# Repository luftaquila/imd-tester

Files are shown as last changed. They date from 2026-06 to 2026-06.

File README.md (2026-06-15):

# IMD Tester

Insulation-fault simulator for verifying Insulation Monitoring Devices (IMD): switches a known resistance between an HV rail and chassis to confirm the IMD trips at its rated threshold. Uses a FNIRSI LCR-ST1 as the ohmmeter.

## Threshold

```
R_th = 250 Ω/V × U_max
```

## Bill of materials

| # | Item | Spec | Qty |
| - | ---- | ---- | --- |
| 1 | LA42DWQ-22 pot | 200 kΩ, 22 mm panel | 1 |
| 2 | Banana jack, 4 mm | red + black, Ø8 mm hole | 2 |
| 3 | Banana cable | red/black pair, clip leads | 1 |
| 4 | MTS-203 toggle | DPDT, ON-OFF-ON, 6 mm bushing | 1 |
| 5 | FNIRSI LCR-ST1 | tweezer LCR meter | 1 |
| 6 | 3D-printed housing | shell + baseplate + button (`housing.scad`) | 1 set |
| 7 | M2 self-tapping screw | ~6 mm, pan/cap head | 4 |

## Circuit

- Pot as rheostat (W + CCW; CW tied to W).
- DPDT toggle routes both pot terminals to one destination:
  - **MEASURE** — LCR-ST1 terminals (set R, HV-isolated)
  - **OFF** (centre) — all open
  - **TEST** — banana jacks (to system)

| Toggle | Net |
| --- | --- |
| COM A / COM B | pot W / pot CCW |
| MEASURE | LCR pad 1 / pad 2 |
| TEST | banana RED / BLACK |

Verify lever→lug mapping and that centre is fully open with a multimeter.

## Procedure

1. **OFF**, cable disconnected.
2. **MEASURE** — set knob to R_th, read on LCR-ST1.
3. **OFF**.
4. Connect RED → HV, BLACK → chassis/GLV.
5. **TEST** briefly; observe IMD response.
6. **OFF**, then disconnect.

## Safety

- Set the resistance in MEASURE (HV-isolated); only TEST connects to the system.
- TEST applies the resistance across live HV — follow HV work procedures.

## Housing (`housing.scad`)

Parametric, 3 printed parts. The LCR-ST1 docks face-up (screen through the top window), inserted from the open bottom; the baseplate closes it with 4 corner M2 self-tapping screws.

- **shell** — top panel + walls; holes for pot (Ø22.5 + anti-rotation notch), toggle (Ø6.2), 2 banana jacks (Ø8, 30 mm pitch), USB-C, display window (bezel + lip); captive-button pocket; 2 banana-plug parking sockets embedded in the front (−Y) face, bottom-right (grip the Ø9×12 plug body + Ø4 pin).
- **baseplate** — fits inside the walls; central LCR support post; 4 recessed M2 clearance holes (Ø1.75 pilot in the shell bosses).
- **button** — captive plunger pressing the LCR power button.

```bash
openscad -D 'part="shell"'     -o shell.stl     housing.scad
openscad -D 'part="baseplate"' -o baseplate.stl housing.scad
openscad -D 'part="button"'    -o button.stl    housing.scad
```

Other `part` values: `preview`, `assembly`, `interference`. Edit the parameter block to match measured parts before printing.

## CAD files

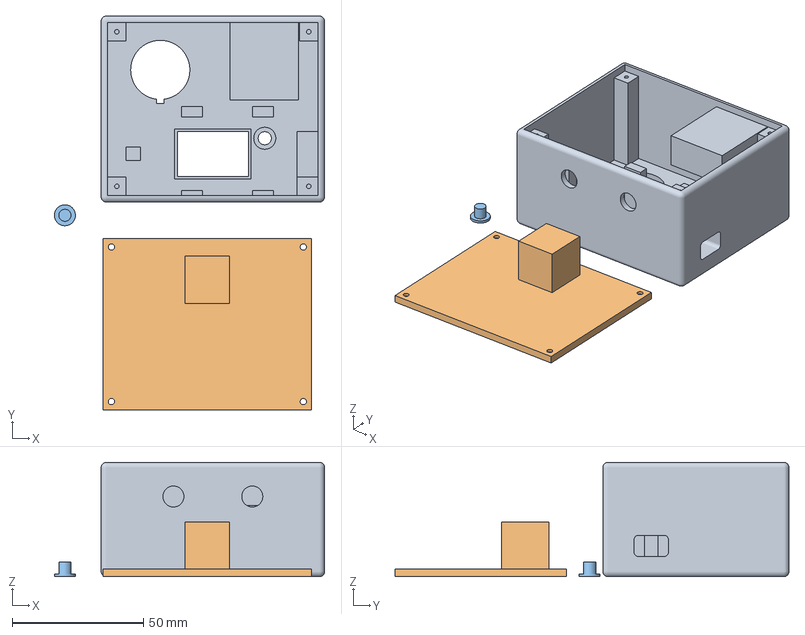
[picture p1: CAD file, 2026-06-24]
housing.3mf
102.8 x 149.9 x 43.5 mm
housing.stl_1
housing.stl_2
housing.stl_3

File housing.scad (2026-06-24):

// ============================================================
//  IMD Tester — integrated enclosure (flat top, no step)
//
//  3 printed parts:
//    shell     : top + walls, OPEN bottom (뚜껑 + 옆면)
//    baseplate : closes the bottom, fits inside the walls (바닥판)
//                4 corner M2 self-tap bolts (heads recessed) + 1 central LCR-support post
//    button    : captive LCR power-button plunger
//
//  Layout: LCR-ST1 in the +Y (back) half, screen up through the top window.
//  Pot + toggle on the top, -Y (front) strip, straddling the X-centre. Banana
//  jacks on the +Y (back) wall; a 2-socket banana-plug parking holder is
//  embedded in the -Y (front) face (bottom-right). Flat top (the pot's ~36 mm
//  body is swallowed by the box height — no step / tower).
//
//  Tweezer ARMS removed by the user, so the box length = LCR body + a small -X
//  wiring lead (measurement wires exit the LCR's -X end). The LCR is raised on
//  a baseplate post so its face seats on the bezel fence, 1.0 mm below the top
//  window; the captive power button is captured in a local panel counterbore.
//
//  Device frame: X = LCR length (+X = USB-C end), Y = width, Z = up.
//  VERIFY all dimensions against the real parts.
// ============================================================

/* [Part selection] */
part = "assembly"; // [shell, baseplate, button, assembly, preview, interference]

/* [LCR-ST1 body] */
lcr_len  = 60;
lcr_wid  = 27.8;
lcr_hi   = 19.2;
lcr_lead = 12;  // -X wiring lead room — trimmed so the screen centres in X

/* [Shell] */
wall      = 2.5;
top_th    = 2.5;
plate_th  = 3.0;
plate_fit = 0.3;

/* [Pot — LA42DWQ-22, top-mounted in the -Y strip] */
pot_depth   = 36;   // body behind the panel
pot_body_d  = 29;   // body diameter inside the box (안쪽, measured)
pot_knob_d  = 31;   // knob outer diameter above the panel (바깥, measured)
pot_clear   = 2;    // gap below the pot body
pot_hole_d  = 22.5; // panel bushing cutout
pot_notch_w = 3;    // anti-rotation notch
pot_notch_d = 1.5;
pot_pos     = [8, -18];  // [x, y] knob centre (balanced about X-centre 28, ±20)

/* [Toggle — MTS-203, top, -Y strip] */
tog_hole_d = 6.2;
tog_pos    = [48, -18]; // balanced about X-centre 28 (same 20 mm as the pot)

/* [Banana jacks — +Y (back) wall, below the LCR] */
jack_d     = 8;    // 7 mm passes, 10 mm flange stops (7 < Ø8 < 10)
jack_body_d = 11;  // jack body Ø inside the box (assumed) — drives support clearance
jack_pitch = 30;   // centre-to-centre
jack_depth = 20;   // jack housing depth inside the box (measured)
jack_xc    = 28;   // pair centre = housing X-centre (jacks symmetric L/R)
jack_z     = 10;   // below the LCR back (Z 18.4); jack body tucks under the LCR

/* [Banana-plug parking sockets — 2x, EMBEDDED in the -Y (front) face, bottom-right; insert +Y; grips the Ø9x12 rubber body] */
park_pin_d    = 4.0;    // contact-pin bore Ø
park_pin_len  = 18;     // contact-pin bore depth (metal pin = 18 mm)
park_grip_d   = 9.0;    // rubber-body bore Ø (per spec)
park_grip_len = 12;     // rubber-body grip length (per spec)
park_wall     = 2;      // material around the bores
park_xs       = [41, 54];// two socket X positions (side by side / horizontal), toward the right
park_z        = 7;       // socket height (low / bottom)

/* [LCR power button + captive plunger] */
pb_w_x = 4.5; pb_w_y = 6;
pb_cx  = lcr_len - 10 - pb_w_x / 2; // 47.75
pb_cy  = 5 + pb_w_y / 2;            // 8.0
pb_protrude = 0.5;
cb_flange_d = 8.0; cb_flange_h = 1.0;  // big flange (full length): bottom on the LCR button, top floats 0.5 mm below the deepened counterbore shoulder
cb_stem_d   = 4.6; cb_hole_d   = 5.0;
cb_cbore_d  = 8.4; cb_stem_out = 2.5;  // counterbore (1.0 deep = flange 0.5 + cb_play 0.5) captures the flange; stem protrudes 2.5 mm above the top

/* [LCR support post (single, centred, on the baseplate)] */
post_jack_clear = 1;  // clearance from each Ø11 jack body
// widest block that clears the two jack bodies: gap between bodies minus clearance
lcr_post_x = jack_pitch - jack_body_d - 2 * post_jack_clear;  // 17 (x 19.5..36.5)
lcr_post_y = 18;                                              // Y length of the support post

/* [Corner bolts — M2, square corner pillars] */
boss_r       = 3.5;  // pilot offset from the inner walls (= bolt hole position)
boss_sq      = 7;    // how far the square pillar reaches into the cavity
boss_pilot_d = 1.75; // M2 self-tap pilot
boss_pilot_h = 9;
m2_clear_d   = 2.4;
m2_head_d    = 4.0;
m2_head_h    = 2.0;

/* [LCR grips] */
grip_xR  = lcr_len - 13; // 47 (Y-grip stations on the long sides)
grip_xL  = 20;
grip_w   = 8;            // Y-grip width along X
grip_th  = 4;            // -Y grip rib thickness (Y) — strengthened from 2 mm (pot-limited)
xgrip_w  = 5;            // X-stop width (Y)
xstop_th = 5;            // X-stop thickness (X, butting the LCR end face)
xstop_squeeze = 0.4;     // -X stop bites this far past the LCR -X face (0.8→0.4, moved back 0.4 mm for clearance)

/* [Screen window] (display 15..41 x 5.5..22.3); bezel shrinks the cutout 1.5 mm/side */
scr_x0 = 14.5; scr_x1 = 41.5;
scr_y0 = 5.5;  scr_y1 = 22.5;

/* [Display bezel fence] thin lip on the panel underside; the LCR face seats on it,
   levelling the meter against its proud (0.5 mm) power button */
fence_h = 1.0;  // protrusion below the panel underside (LCR sits 1.0 mm below the panel)
fence_w = 1.0;  // fence wall width around the window

/* [USB-C cutout, right wall] */
usb_w = 13; usb_h = 8; usb_r = 1.5; // rounded corners (W,H +1 each, centre kept)
usb_frame_w = 2.0;                  // +X stop border around the USB (wraps the port on all sides)

/* [Edge rounding] */
edge_r  = 2;   // fillet on all outer edges (top, vertical, and bottom -Z)

/* [Engraving — recessed (음각) labels on the top] */
engrave_depth = 0.5;
txt_formula   = "250 Ω / V";
txt_sw_a      = "SET";      // +Y toggle position
txt_sw_off    = "OFF";
txt_sw_b      = "TEST";     // -Y toggle position
txt_pwr       = "PWR";
formula_pos   = [8, -34];   // below the pot

/* [Rendering] */
$fn     = 64;
explode = 45;
eps     = 0.1;

// ---------- derived heights ----------
roof_z0 = pot_depth + pot_clear;   // 38   top-panel underside
roof_z1 = roof_z0 + top_th;        // 40.5 top
face_z  = roof_z0 - fence_h;       // LCR face seats on the bezel fence, 1.0 mm below the panel
post_h  = face_z - lcr_hi;         // 18.4 LCR rests on the baseplate post at this Z

cb_flange_z0 = face_z + pb_protrude;          // flange bottom = LCR-button contact level (full-length plunger restored)
cb_flange_z1 = cb_flange_z0 + cb_flange_h;    // flange top (38.5)
cb_play      = 0.5;                            // counterbore deepened past the flange top → plunger floats 0.5 mm, no button preload
cb_cbore_z1  = cb_flange_z1 + cb_play;         // counterbore shoulder (39.0; cbore now 1.0 deep, +0.5)
cb_stem_z1   = roof_z1 + cb_stem_out;

usb_cy = lcr_wid / 2;       // width-centred
usb_z  = post_h + 11;       // 11 mm above the device back

// ---------- interior / outer ----------
cav_x0 = -lcr_lead;         // -12 (no tweezers; just wiring lead room)
cav_x1 = lcr_len + 8;       // 68 (USB-C wall pad)
cav_y0 = -36;               // front strip (pot/toggle); fits the Ø29 pot body
cav_y1 = lcr_wid + 2;       // 29.8 back

out_x0 = cav_x0 - wall; out_x1 = cav_x1 + wall;
out_y0 = cav_y0 - wall; out_y1 = cav_y1 + wall;
out_z0 = -plate_th;

// corner bolts (box corners, clear of the LCR)
boss = [
    [cav_x0 + boss_r, cav_y0 + boss_r],
    [cav_x1 - boss_r, cav_y0 + boss_r],
    [cav_x0 + boss_r, cav_y1 - boss_r],
    [cav_x1 - boss_r, cav_y1 - boss_r],
];

// ---------- shell ----------

module rounded_outer() { // box with ALL edges rounded (top, vertical, and bottom -Z)
    r = edge_r;
    hull() for (x = [out_x0 + r, out_x1 - r], y = [out_y0 + r, out_y1 - r]) {
        translate([x, y, roof_z1 - r]) sphere(r = r);  // top corners
        translate([x, y, out_z0 + r]) sphere(r = r);   // bottom corners (rounded -Z)
    }
}

module engrave(str, pos, sz) { // recessed text on the top surface
    translate([pos[0], pos[1], roof_z1 - engrave_depth])
        linear_extrude(engrave_depth + 1)
            text(str, size = sz, halign = "center", valign = "center",
                 font = "Liberation Sans:style=Bold");
}

module grip(xc, side) { // Y-grip: rib hugging a LONG side of the LCR
    th    = (side < 0) ? grip_th : cav_y1 - lcr_wid; // -Y: thick rib; +Y: fills LCR↔wall gap (wall-backed)
    yEdge = (side < 0) ? 0 : lcr_wid;
    ribY  = (side < 0) ? yEdge - th : yEdge;
    translate([xc - grip_w / 2, ribY, post_h])
        cube([grip_w, th, roof_z0 - post_h]);
}
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

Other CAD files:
housing.stl

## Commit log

2026-06-13 add: IMD tester housing (OpenSCAD) and README
    Parametric 3-part enclosure (shell, baseplate, captive button) for a
    FNIRSI LCR-ST1 based insulation-fault simulator: LA42DWQ-22 pot, MTS-203
    DPDT toggle (MEASURE/OFF/TEST), 2 banana jacks. 250 Ω/V threshold.
    [housing.scad]
2026-06-15 add: banana-plug parking holder; fix stale comments/README
    - 2-socket parking holder on the +X wall (grips the Ø9x12 plug body + Ø4x18
    pin), merged with the body into one seamless rounded shell (bottom -Z
    rounded too, no crease at the junction)
    - correct stale header/inline comments and README to match the design;
    remove the unused lcr_fit parameter
    [housing.scad]
2026-06-15 change: embed the parking holder in the front (-Y) face
    - move the 2 banana-plug parking sockets from an external +X-wall block into
    the body: now an internal block in the front strip, bottom-right (only two
    holes show on the -Y face, no protrusion)
    - arrange the two sockets side by side (horizontal) at the same height
    - update header comment and README to match
    - gitignore .DS_Store
    [housing.scad]
2026-06-23 change: raise display bezel fence protrusion 0.4 -> 1.0 mm
    LCR face now seats 1.0 mm below the top window; support post height
    follows automatically via post_h = face_z - lcr_hi.
    [housing.scad]
2026-06-24 change: shave button plunger bottom 0.5 mm and pull -X stop back 0.4 mm
    - button: flange bottom raised to the panel underside (1.0->0.5 mm), 0.5 mm
    clear of the LCR power button (removes preload)
    - -X stop: xstop_squeeze 0.8->0.4 mm for LCR end-face clearance
    [housing.scad]
2026-06-24 change: restore full plunger, deepen button counterbore 0.5 mm instead
    Keep the 1.0 mm flange (sturdier than the shaved 0.5 mm) and get the
    0.5 mm float from the housing side: decouple the counterbore shoulder
    from the flange top (cb_play / cb_cbore_z1) so the cbore is 1.0 mm deep.
    Plunger no longer preloads the LCR power button.
    [housing.scad]
2026-06-24 add: stl and 3mf
    [housing.3mf, housing.stl]
